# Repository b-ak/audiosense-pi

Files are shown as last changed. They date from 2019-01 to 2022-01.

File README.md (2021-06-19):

## AudioSense-Pi

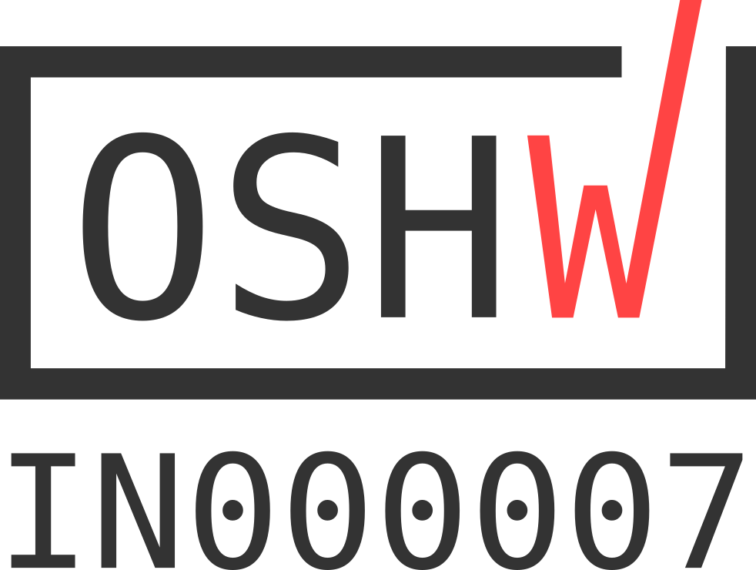
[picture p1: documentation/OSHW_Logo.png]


**[AudioSense-Pi](https://certification.oshwa.org/in000007.html)** is a RPi HAT based on a TI's stereo codec.  
It is **Open Source Harwdare Association (OSHWA)** certified with **_UID - IN000007_**  

This hardware provides audio input capabilities to the RPi.   
The codec connects to the RPi's SoC through the I2S Bus.

_The codec chosen, allows interfacing **multiple audio I/O** to the RPi._   

**Multiple I/O?** _Yes!_   
The following devices can be connected through a 3.5mm jack
1. Line-In: Plain old audio in from mobile phones, PCs, etc.,
2. Mic-In: Connect a microphone
3. Line-Out: Connect the output to a speaker
4. Headphones: Connect a Headphone w or w/o microphones

**Simultaneous Inputs?** _Yes!_    
It supports the following combinations
1. Two stereo Line-Inputs and a microphone
2. One stereo Line-Input and two microphones
3. Two stereo Line-Inputs, a microphone and one mono line-input (with h/w hack)
4. One stereo Line-Input, two microphones and one mono line-input (with h/w hack)

**Simultaneous Outputs?** _Yes!_   
Audio output can be routed to the headphones or speakers (with additional hardware)

#### Hardware overview       
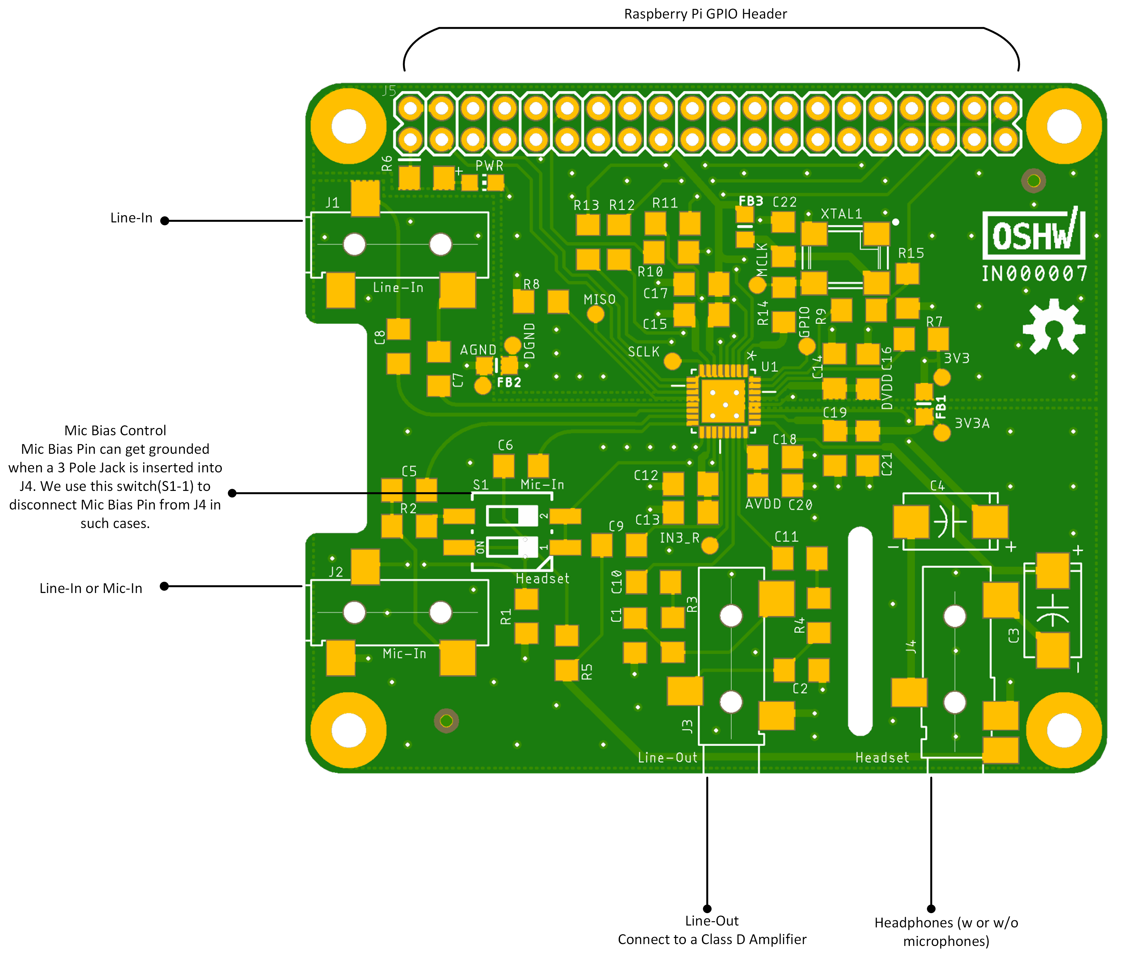
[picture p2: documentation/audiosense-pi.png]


#### Software overview   
Using the ALSA System on Chip (ASoC) layer we write a machine driver for the HAT.   
With the following changes a new sound card by the name `audiosense-pi` will appear
1. A device tree overlay is added for hardware configuration.
2. Changes to the configuration file (config.txt).
3. ASoC machine driver, makefile and kconfig changes
4. Minimal changes to the ASoC codec driver to handle deprecated APIs

## Getting started with AudioSense-Pi

#### Fab
1. Order the [BOM](./hardware/AudioSense-Pi_BOM.ods)
2. Send the [gerber files](./hardware/audiosense-pi-gerber.zip) to your nearest fab house
3. Assemble the board, it should look something like this..

Assembled Board    
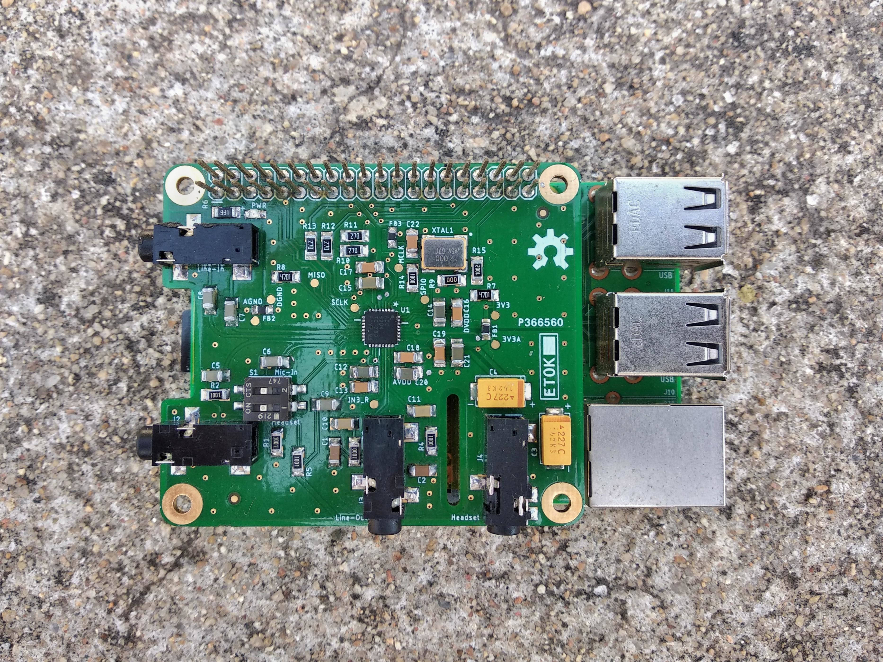
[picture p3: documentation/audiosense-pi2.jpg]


#### Preparing the SD card

We have three ways to setup audiosense
1. Get the [prebuilt images](https://drive.google.com/file/d/10sPdlaTlowZFA2HO4iOQT1hiyIX3uXNR/view?usp=sharing), flash it into a SD card, fly away!
2. Stay with the existing image you have, build the kernel yourself and flash only the kernel image
    * Pull the raspberry pi [kernel source](https://github.com/raspberrypi/linux.git)
    * Use [this](https://github.com/b-ak/helper-scripts/blob/master/rpi3-kernel-builder.sh) script to build and flash the kernel image to the SD card
    * Edit/add the following lines to the `config.txt` in the boot partiton of the SD card
    ```
        # Uncomment some or all of these to enable the optional hardware interfaces
        dtparam=i2c_arm=on
        dtparam=i2s=on
        dtparam=spi=on
        
        # Uncomment this to enable the lirc-rpi module
        #dtoverlay=lirc-rpi
        
        # Additional overlays and parameters are documented /boot/overlays/README
        dtoverlay=audiosense-pi

        # Enable audio (loads snd_bcm2835)
        dtparam=audio=on
    ```    
    * Boot the pi, run the command `aplay -l` you should see a new soundcard `audiosense-pi`
3. Get a kernel image that you want, merge the patches manually, build and flash the kernel image (*for advanced kernel developers*)
    * Clone the kernel sources you want
    * Apply the patches in the [software directory](./software) (`git am` might not work owing to the large number of changes among the trees)
    * Use the script in step 2, apply the `config.txt` changes and boot the pi

#### Configuring the soundcard
1. Open terminal, type in `alsamixer`. Hit `F6` and select `audiosense-pi` from the list of soundcards
	Soundcard selection    
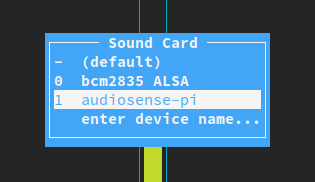
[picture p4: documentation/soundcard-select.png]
	
2. Soundcard widgets and control settings    
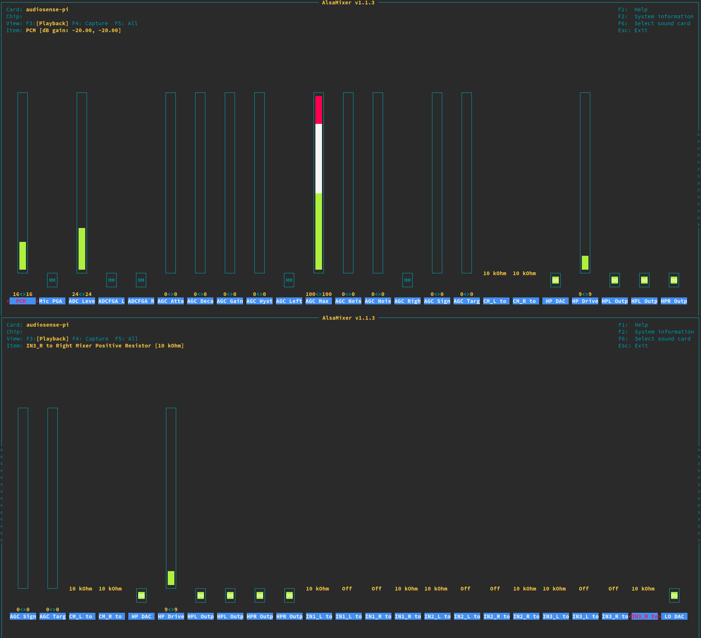
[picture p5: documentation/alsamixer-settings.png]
	
3. Plug in an audio-input to the board, a headphones and run `arecord -D hw:1 -c 2 -r 48000 -f S16_LE | aplay -D hw:1`
4. If you did everything right, you will be listening to your favourite song ;)

## License Information  

*Hardware* licensed under the _CERN Open Hardware License version 1.2_   
*Software* licensed under the _GNU GPLv2_   
*Documentation* licensed under _CC0 1.0 Universal_

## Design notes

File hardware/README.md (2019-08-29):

## AudioSense-Pi Hardware 

**Schematics**       


**Board**       


**PCB Top**       


**PCB Bottom**       


**Assembly**      
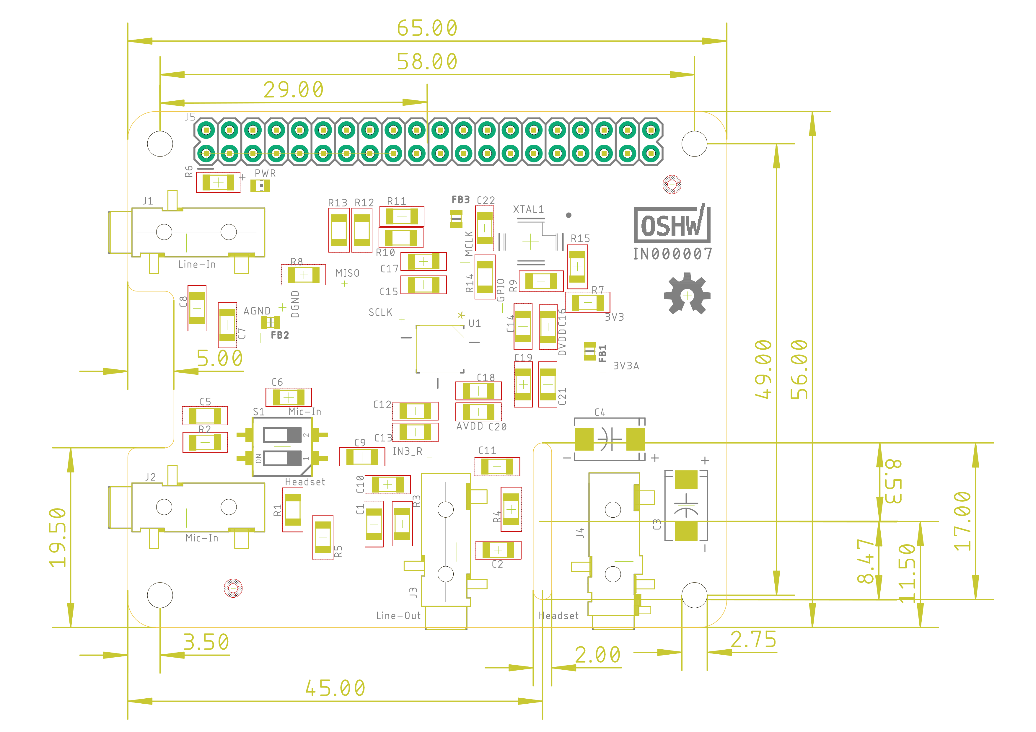
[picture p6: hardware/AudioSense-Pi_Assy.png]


## License Information  

*Hardware* licensed under the _CERN Open Hardware License version 1.2_   
*Software* licensed under the _GNU GPLv2_   
*Documentation* licensed under _CC0 1.0 Universal_

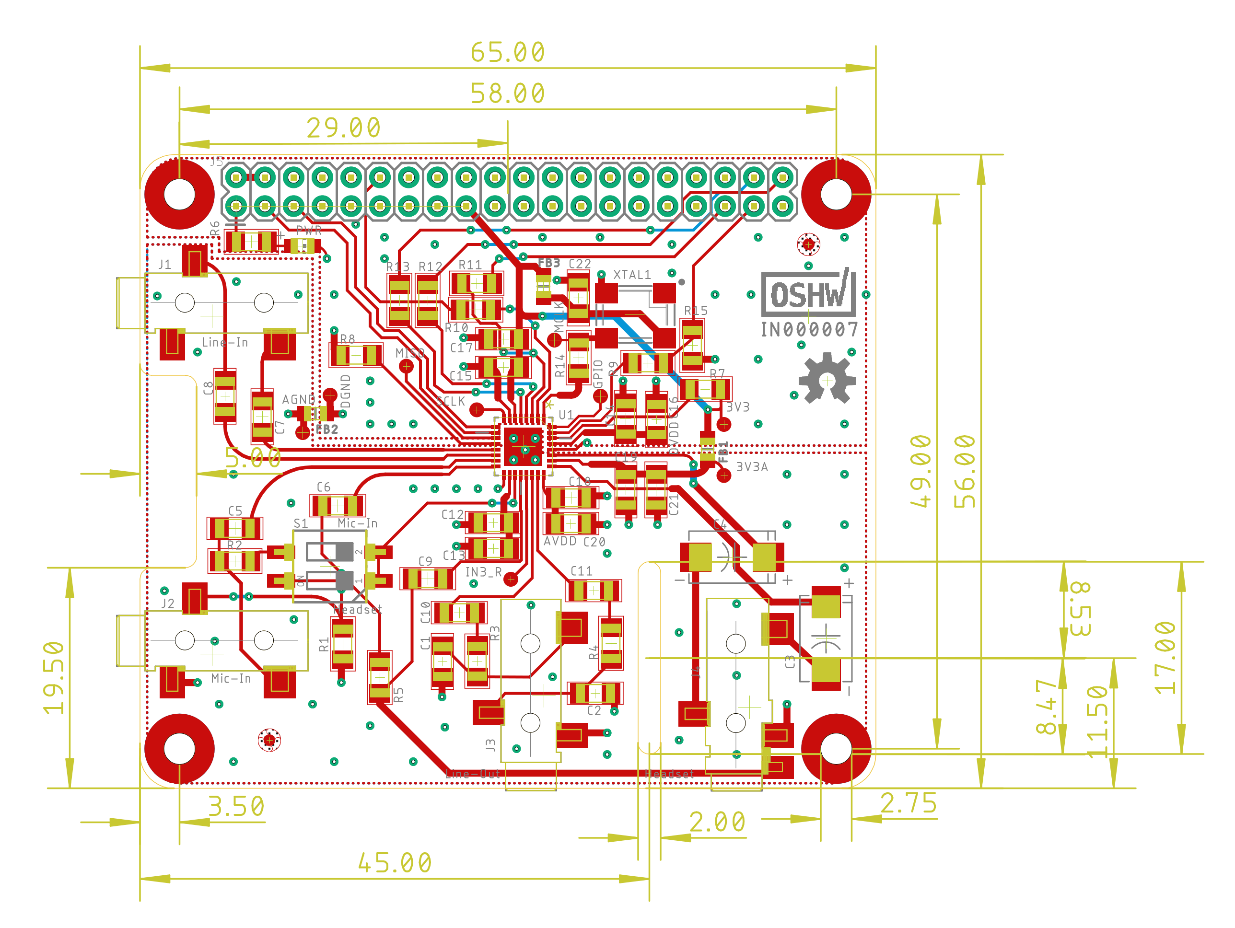
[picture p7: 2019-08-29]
documentation/AudioSense-Pi_Brd.png

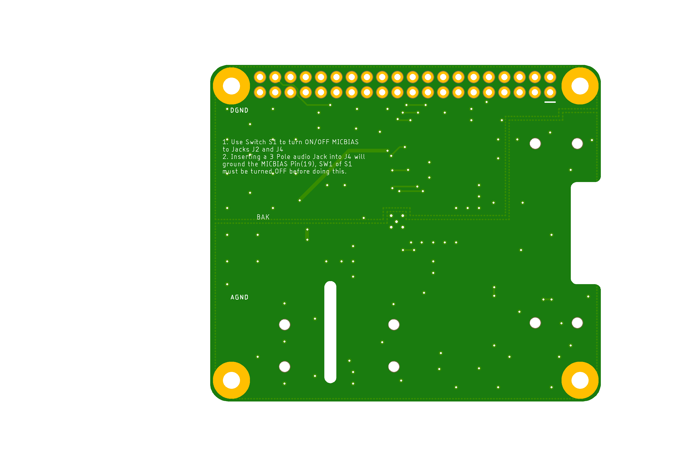
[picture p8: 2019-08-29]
documentation/AudioSense-Pi_PCB_Bot.png

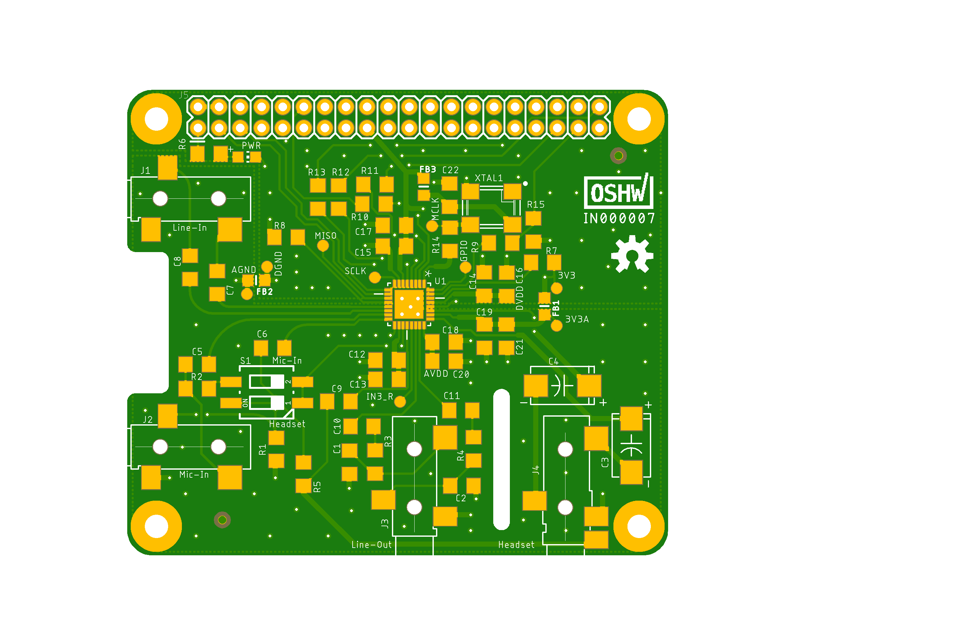
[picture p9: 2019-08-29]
documentation/AudioSense-Pi_PCB_Top.png

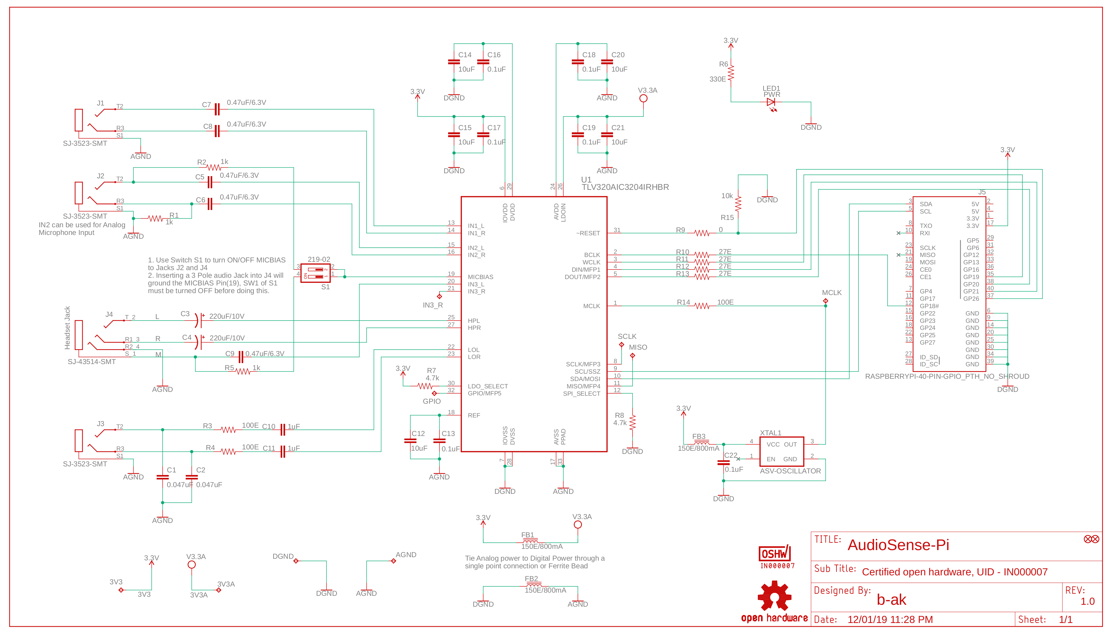
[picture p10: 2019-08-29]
documentation/AudioSense-Pi_Sch.png

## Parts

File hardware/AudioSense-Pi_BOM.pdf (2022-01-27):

### Page

Qty | Value | Parts | DESCRIPTION | MANUFACTURER | MANUFACTURER_PART_NUMBER | PACKAGE
9 | TPB1,27 | 3V3, 3V3A, AGND, DGND, GPIO, IN3_R, MCLK, MISO, SCLK
6 | 0.1uF | C13, C16, C17, C18, C19, C22 | CAP CER 0.1UF 16V X7R 1206 | Kemet | C1206C104K4RACTU | 1206
5 | 0.47uF/6.3V | C5, C6, C7, C8, C9 | CAP CER 0.47UF 16V X7R 1206 | Yageo | CC1206KRX7R7BB474 | 1206
5 | 10uF | C12, C14, C15, C20, C21 | CAP CER 10UF 16V X7R 1206 | Kemet | C1206C106J4RACTU | 1206
4 | 27E | R10, R11, R12, R13 | RES SMD 27 OHM 5% 1/4W 1206 | Yageo | RC1206JR-0727RL | 1206
3 | 100E | R3, R4, R14 | RES SMD 100 OHM 1% 1/4W 1206 | Yageo | RC1206FR-07100RL | 1206
3 | 150E/800mA | FB1, FB2, FB3 | FERRITE BEAD 150 OHM 0805 1LN | Murata Electronics North America | BLM21AG151SN1D | 0805 (2012 Metric)
3 | 1k | R1, R2, R5 | RES SMD 1K OHM 1% 1/4W 1206 | Yageo | RC1206FR-071KL | 1206
3 | SJ-3523-SMT | J1, J2, J3 | CONN JACK STEREO 3.5MM SMD R/A | CUI Inc. | SJ-3523-SMT-TR | Surface Mount, Right Angle
2 | 0.047uF | C1, C2 | CAP CER 0.047UF 10V X7R 1206 | AVX Corporation | 1206ZC473KAT2A | 1206
2 | 1uF | C10, C11 | CAP CER 1UF 16V X7R 1206 | Yageo | CC1206JKX7R7BB105 | 1206
2 | 220uF/10V | C3, C4 | CAP TANT 220UF 10V 10% 2917 | KEMET | T491D227K010AT | 2917 (7343 Metric)
2 | 4.7k | R7, R8 | RES SMD 4.7K OHM 1% 1/4W 1206 | Yageo | RC1206FR-074K7L | 1206
2 | FIDUCIAL" | FID1, FID2
1 | 0 | R9 | RES SMD 0 OHM JUMPER 1/4W 1206 | Yageo | AC1206JR-070RL | 1206
1 | 10k | R15 | RES SMD 10K OHM 1% 1/4W 1206 | Yageo | RC1206FR-0710KP | 1206
1 | 219-02 | S1 | SWITCH SLIDE DIP SPST 100MA 20V | CTS Electrocomponents | 219-2LPSTR | SMT
1 | 330E | R6 | RES SMD 330 OHM 5% 1/4W 1206 | Yageo | RC1206JR-07330RL | 1206
1 | ASV-OSCILLATOR | XTAL1 | OSC XO 12.000MHZ HCMOS SMD | Abracon LLC | ASV-12.000MHZ-EJ-T | 1206
1 | LED1 | PWR | | Lite-On Inc. | | 0805 (2012 Metric)
1 | OSHW-LOGOL | LOGO1
1 | RASPBERRYPI-40-PIN-GPIO_PTH_NO_SHROUD | J5 | Stacking Header for Pi A+/B+/Pi 2/Pi 3 -2x20 Extra Tall Header | Adafruit | 1979 | PTH
1 | SJ-43514-SMT | J4 | CONN JACK 4COND 3.5MM SMD R/A | CUI Inc. | SJ-43514-SMT-TR | Surface Mount, Right Angle
1 | TLV320AIC3204IRHBR | U1 | IC STEREO AUDIO CODEC 1.8V 32QFN | Texas Instruments | TLV320AIC3204IRHBR | 32-VFQFN Exposed Pad

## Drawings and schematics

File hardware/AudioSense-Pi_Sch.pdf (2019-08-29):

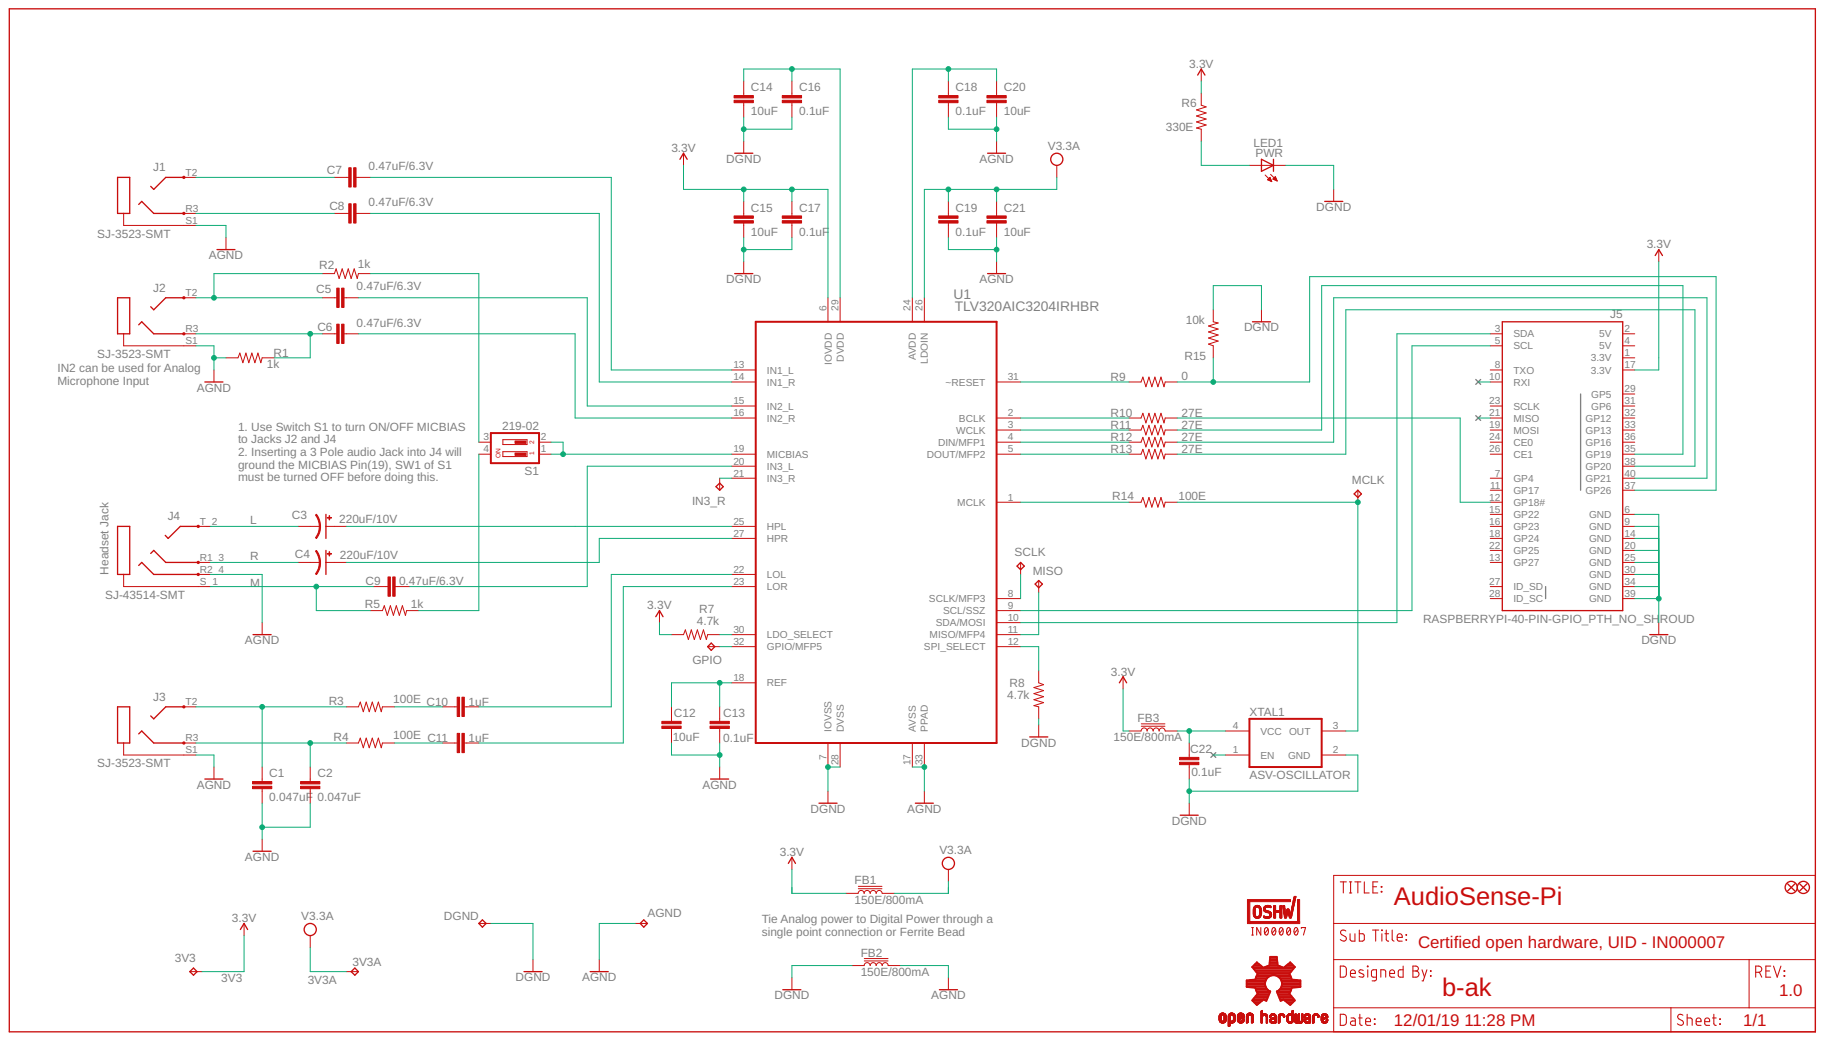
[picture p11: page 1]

IN2 can be used for Analog Microphone Input

1. Use Switch S1 to turn ON/OFF MICBIAS
to Jacks J2 and J4
2. Inserting a 3 Pole audio Jack into J4 will ground the MICBIAS Pin(19), SW1 of S1 must be turned OFF before doing this.

Tie Analog power to Digital Power through a
single point connection or Ferrite Bead

Certified open hardware, UID - IN000007

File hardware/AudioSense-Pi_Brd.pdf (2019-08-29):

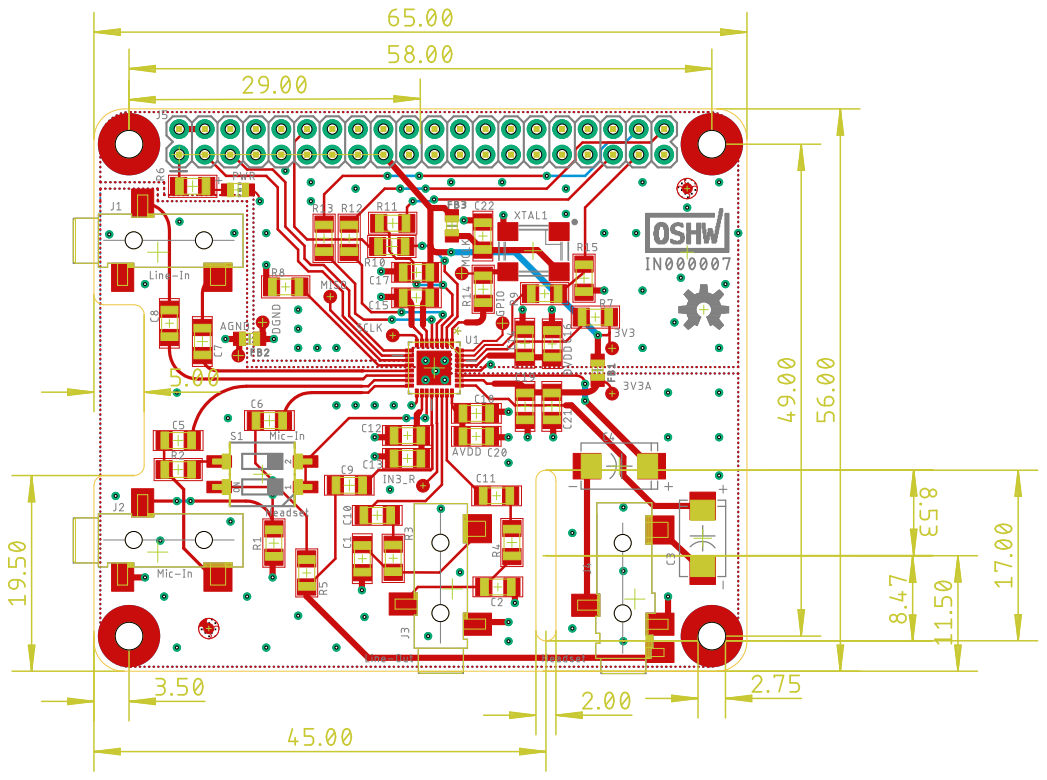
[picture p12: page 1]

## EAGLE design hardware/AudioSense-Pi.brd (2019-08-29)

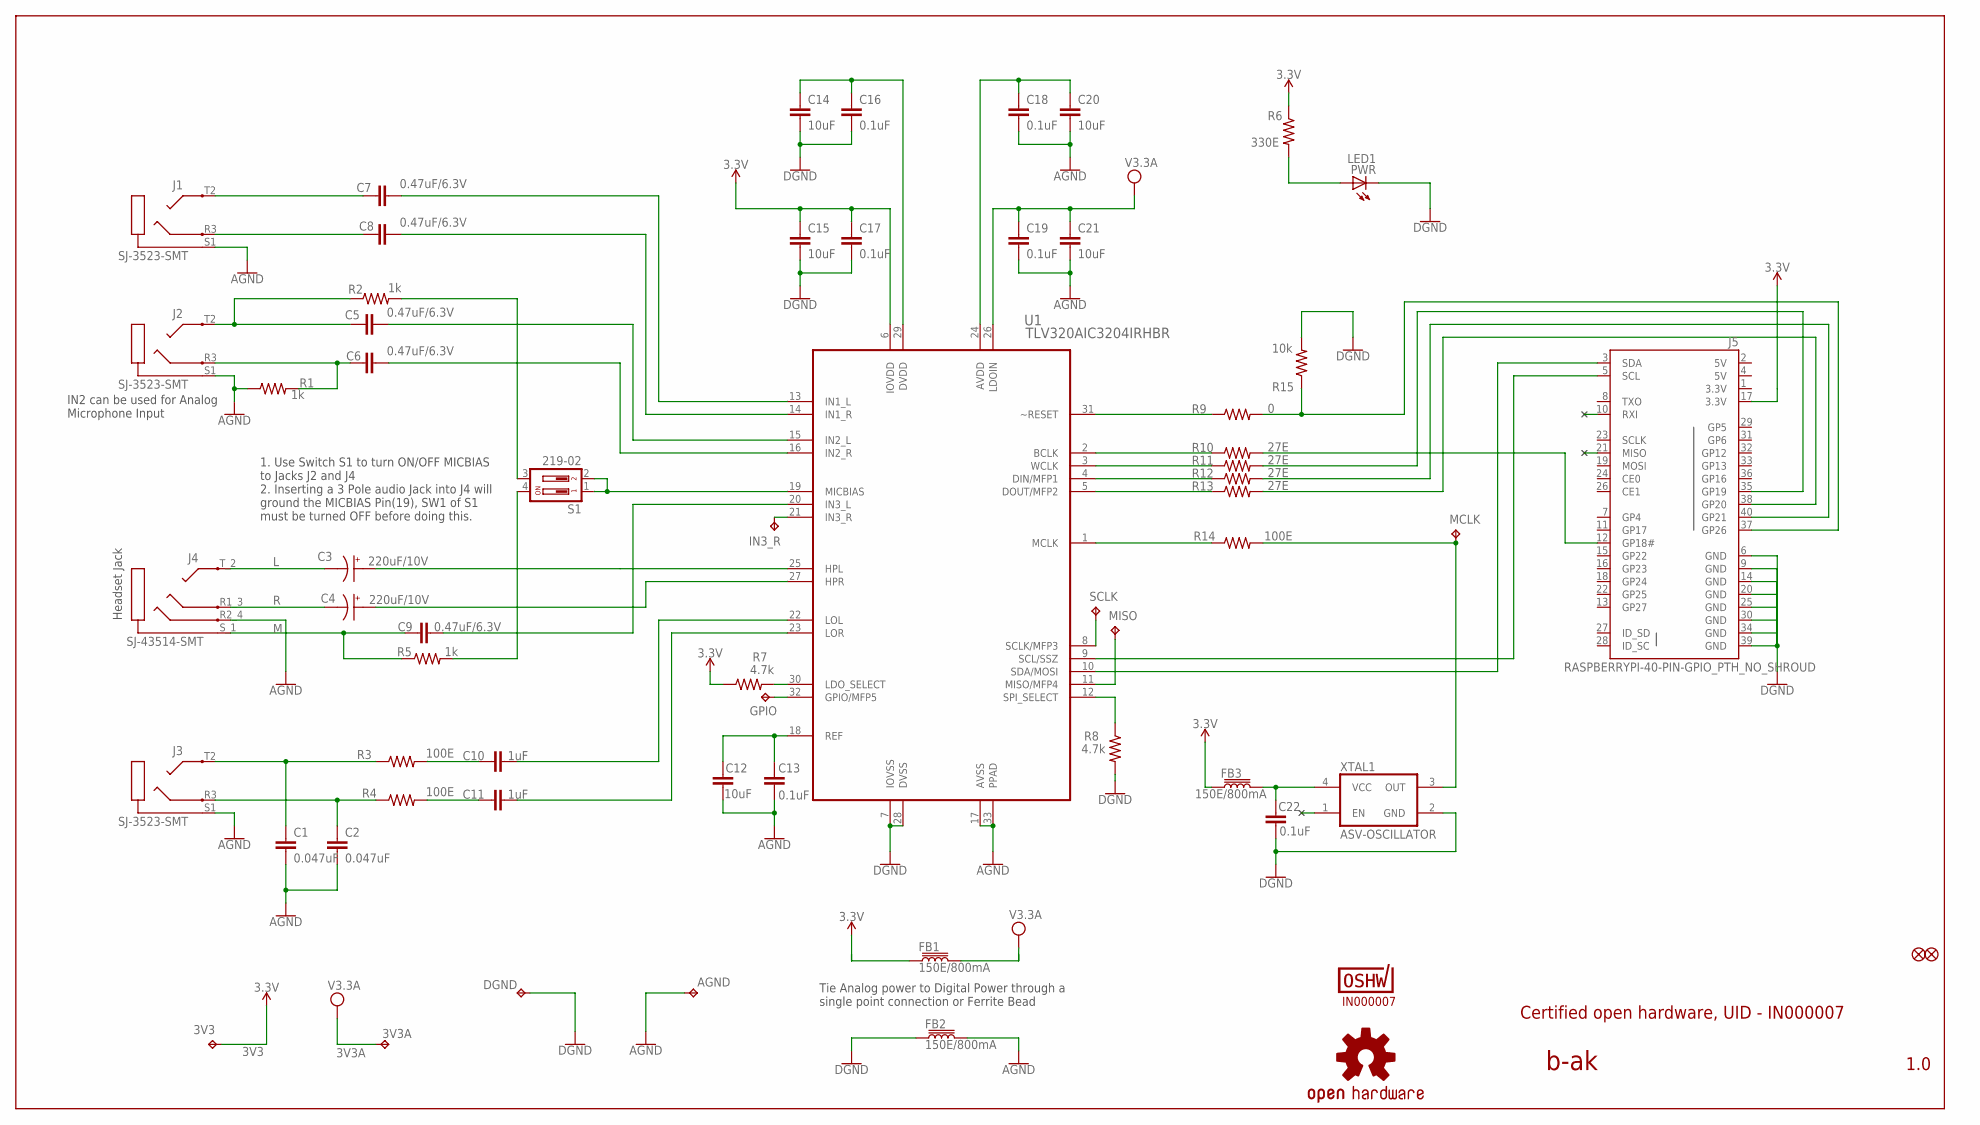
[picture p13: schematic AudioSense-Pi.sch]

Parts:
3V3, 3V3A: TPB1,27; B1,27
AGND: TPB1,27; B1,27
C1, C2: 0.047uF; C1206; MANUFACTURER_PART_NUMBER 1206ZC473KAT2A
C3, C4: 220uF/10V; D; MANUFACTURER_PART_NUMBER T491D227K010AT
C5, C6, C7, C8, C9: 0.47uF/6.3V; C1206; MANUFACTURER_PART_NUMBER CC1206KRX7R7BB474
C10, C11: 1uF; C1206; MANUFACTURER_PART_NUMBER CC1206JKX7R7BB105
C12, C14, C15, C20, C21: 10uF; C1206; MANUFACTURER_PART_NUMBER C1206C106J4RACTU
C13, C16, C17, C18, C19, C22: 0.1uF; C1206; MANUFACTURER_PART_NUMBER C1206C104K4RACTU
DGND: TPB1,27; B1,27
FB1, FB2, FB3: 150E/800mA; _0805MP; MANUFACTURER_PART_NUMBER BLM21AG151SN1D
FID1, FID2: FIDUCIAL""; FIDUCIAL_1MM
GPIO: TPB1,27; B1,27
IN3_R: TPB1,27; B1,27
J1, J2, J3: SJ-3523-SMT; MANUFACTURER_PART_NUMBER SJ-3523-SMT-TR
J4: SJ-43514-SMT; MANUFACTURER_PART_NUMBER SJ-43514-SMT-TR
J5: RASPBERRYPI-40-PIN-GPIO_PTH_NO_SHROUD; 2X20; MANUFACTURER_PART_NUMBER 1979
LOGO2: OSHW-LOGOM; OSHW-LOGO-M
MCLK: TPB1,27; B1,27
MISO: TPB1,27; B1,27
PWR: LED1; CHIP-LED0805; MANUFACTURER_PART_NUMBER LTST-C150GKT
R1, R2, R5: 1k; 1206; MANUFACTURER_PART_NUMBER RC1206FR-071KL
R3, R4, R14: 100E; 1206; MANUFACTURER_PART_NUMBER RC1206FR-07100RL
R6: 330E; 1206; MANUFACTURER_PART_NUMBER RC1206JR-07330RL
R7, R8: 4.7k; 1206; MANUFACTURER_PART_NUMBER RC1206FR-074K7L
R9: 0; 1206; MANUFACTURER_PART_NUMBER AC1206JR-070RL
R10, R11, R12, R13: 27E; 1206; MANUFACTURER_PART_NUMBER RC1206JR-0727RL
R15: 10k; 1206; MANUFACTURER_PART_NUMBER RC1206FR-0710KP
S1: 219-02; CTS-219-02
SCLK: TPB1,27; B1,27
U1: TLV320AIC3204IRHBR; QFN50P500X500X100-33N; MANUFACTURER_PART_NUMBER TLV320AIC3204IRHBR
U$6: IN000007; CERT-SMALL-SILK
XTAL1: ASV-OSCILLATOR; OSCILLATOR_7X5_SMD; MANUFACTURER_PART_NUMBER ASV-12.000MHZ-EJ-T

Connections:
3POLE_MBIAS: R2.2, S1.3
3V3: 3V3.TP, C15.1, C17.1, FB1.1, FB3.1, J5.1 (3.3V), J5.17 (3.3V), R6.1, R7.1, U1.6 (IOVDD)
3V3A: 3V3A.TP, C19.1, C21.1, FB1.2, U1.26 (LDOIN)
4POLE_MBIAS: R5.2, S1.4
5V: J5.2 (5V), J5.4 (5V)
AGND: AGND.TP, C1.2, C2.2, C12.2, C13.2, C18.2, C19.2, C20.2, C21.2, FB2.2, J1.S1, J2.S1, J3.S1, J4.R2_4, R1.1, U1.17 (AVSS), U1.33 (PPAD)
AIC_LINE_LOUT_1: C10.1, R3.2
AIC_LINE_ROUT_1: C11.1, R4.2
AVDD: C18.1, C20.1, U1.24 (AVDD)
BCLK: R10.1, U1.2 (BCLK)
DIN: R12.1, U1.4 (DIN/MFP1)
DOUT: R13.1, U1.5 (DOUT/MFP2)
DVDD: C14.1, C16.1, U1.29 (DVDD)
GND: C14.2, C15.2, C16.2, C17.2, C22.2, DGND.TP, FB2.1, J5.6 (GND), J5.9 (GND), J5.14 (GND), J5.20 (GND), J5.25 (GND), J5.30 (GND), J5.34 (GND), J5.39 (GND), PWR.C, R8.2, R15.2, U1.7 (IOVSS), U1.28 (DVSS), XTAL1.2 (GND)
GPIO: GPIO.TP, U1.32 (GPIO/MFP5)
GP_26: J5.37 (GP26), R9.2, R15.1
HPL: C3.+ (A), U1.25 (HPL)
HPR: C4.+ (A), U1.27 (HPR)
IN1L: C7.2, U1.13 (IN1_L)
IN1R: C8.2, U1.14 (IN1_R)
IN1_RING: C8.1, J1.R3
IN1_TIP: C7.1, J1.T2
IN2L: C5.2, U1.15 (IN2_L)
IN2R: C6.2, U1.16 (IN2_R)
IN2_RING: C6.1, J2.R3, R1.2
IN2_TIP: C5.1, J2.T2, R2.1
IN3L: C9.2, U1.20 (IN3_L)
IN3_R: IN3_R.TP, U1.21 (IN3_R)
L: C3.- (C), J4.T_2
LDO_SEL: R7.2, U1.30 (LDO_SELECT)
LED-A: PWR.A, R6.2
LOL: C10.2, U1.22 (LOL)
LOR: C11.2, U1.23 (LOR)
LOUT_RING: C2.1, J3.R3, R4.1
LOUT_TIP: C1.1, J3.T2, R3.1
M: C9.1, J4.S_1, R5.1
MCLK: R14.1, U1.1 (MCLK)
MICBIAS: S1.1, S1.2, U1.19 (MICBIAS)
MISO: MISO.TP, U1.11 (MISO/MFP4)
R: C4.- (C), J4.R1_3
REF: C12.1, C13.1, U1.18 (REF)
RESET: R9.1, U1.31 (~RESET)
RPI_BCLK_PIN12: J5.12 (GP18#), R10.2
RPI_DIN_PIN38: J5.38 (GP20), R13.2
RPI_DOUT_PIN40: J5.40 (GP21), R12.2
RPI_FS_PIN35: J5.35 (GP19), R11.2
SCL: J5.5 (SCL), U1.9 (SCL/SSZ)
SCLK: SCLK.TP, U1.8 (SCLK/MFP3)
SDA: J5.3 (SDA), U1.10 (SDA/MOSI)
SPI_SEL: R8.1, U1.12 (SPI_SELECT)
VCC: C22.1, FB3.2, XTAL1.4 (VCC)
WCLK: R11.1, U1.3 (WCLK)
XTAL_OUT: MCLK.TP, R14.2, XTAL1.3 (OUT)

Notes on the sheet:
Tie Analog power to Digital Power through a single point connection or Ferrite Bead
b-ak
1. Use Switch S1 to turn ON/OFF MICBIAS to Jacks J2 and J4 2. Inserting a 3 Pole audio Jack into J4 will ground the MICBIAS Pin(19), SW1 of S1 must be turned OFF before doing this.
IN2 can be used for Analog Microphone Input
Headset Jack
1.0
Certified open hardware, UID - IN000007

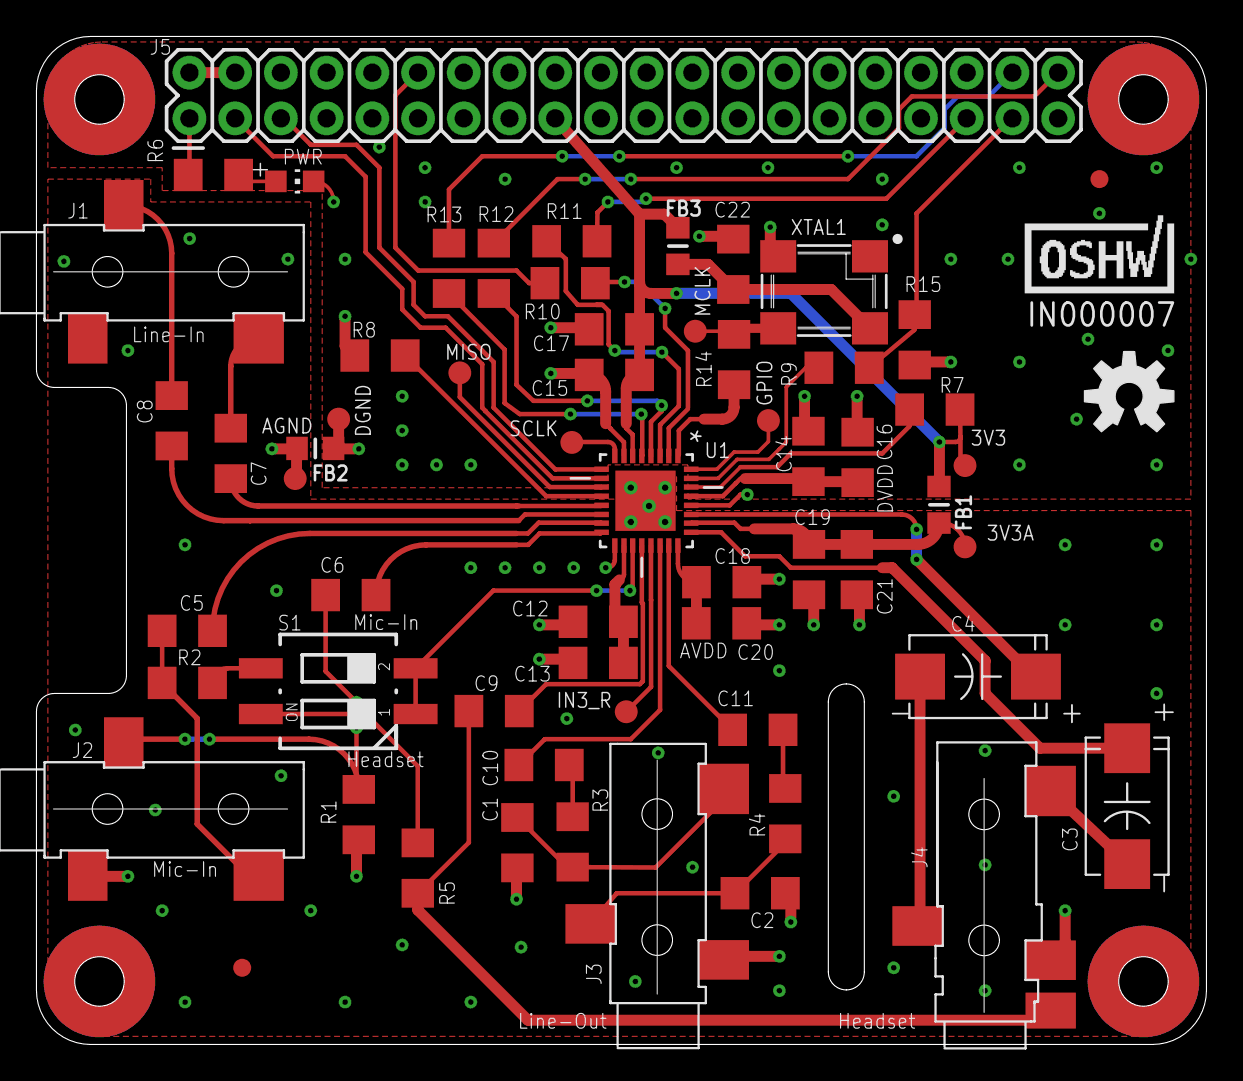
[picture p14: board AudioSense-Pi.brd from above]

Board: 2 copper layers, 65.0 x 56.0 mm, 62 parts (0 on the bottom side), 53 nets.

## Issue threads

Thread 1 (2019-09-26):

No audio on PH and Line output

sawacs, 2019-09-26:
Hi.
My hardware: RaspberryPi 4/4GB with latest Raspbian kernel 4.19.

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

I have two AudioSense-Pi that I have assembled myself.

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

I added all necessary entries to /boot/config.txt:
dtparam=i2c_arm=on
dtparam=i2s=on
dtparam=spi=on
dtoverlay=lirc-rpi
dtoverlay=audiosense-pi

My problem is that there is no audio signal on both headphone and line outputs.

Test i did:

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

1: ffmpeg -i Downloads/1kHz_44100Hz_16bit_30sec.wav -af "pan=stereo|c0=c0|c1=c0" -ar 48000 -f alsa hw:1,0

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

 No audio output! I noticed that "time" increases every two to three seconds and "speed" drops from 0.99 downwards v. fast...
It's the same for both PCBs
Perhaps something is wrong on the PCB, but all the elements were new and I tried to assemble them very carefully!
I'm sure raspbian os recognizes AudioSense-Pi correctly. I carried out the test by giving an audio signal to the LineIn input and switched "Bypass" - HPL / R Output Mixer IN1L / R
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
I heard on the headphones what was on the line input... I2C is working...
OK.
For today I have to finish ...

Maybe someone has an idea where is the problem ....?
Or maybe someone already had such a problem ...?

By

b-ak, 2019-09-28:
Can you try this command `arecord -D hw:1 -c 2 -r 48000 -f S16_LE | aplay -D hw:1`
Connect an audio source to `J2` - `Mic-In` and check what's on your headphones

sawacs, 2019-09-30:
Hi!
There was a problem here
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
... I soldered two resistors R10 and R11 wrongly!
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

Now I'm going to tests ...

b-ak, 2019-10-03:
Great!! Any updates? Have you got it working?

sawacs, 2019-10-04:
I apologize for the short delay in my response ... I was away for a few days.
Yes. I confirm that my tests were successful. Recording works, playback works. Now I am learning the other possibilities of TLV320 ...
Thanks for the help.
... I will try to run modules on OrangePi and NanoPi M4 after some time.

b-ak, 2019-10-06:
Great to know that. Thank you for a detailed report, it'll help other people trying to recreate the board :)

Closed 2019-10-04.

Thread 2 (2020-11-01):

Playback not working, getting input/output error

SlowFamily, 2020-11-01:
I have acquired a Raspberry Pi 3 Model B+ in order to test. Unfortunately, I am still having no success getting audiosense-pi to work. :-(

I am trying to use Linux raspberrypi 4.19.118-v7+ #1311

If I have headphones plugged in when I power it up, I hear a pop, and power light is on, so it is at least getting power.

I see devices like so:

$ aplay -l
**** List of PLAYBACK Hardware Devices ****
card 0: Headphones [bcm2835 Headphones], device 0: bcm2835 Headphones [bcm2835 Headphones]
Subdevices: 8/8
Subdevice #0: subdevice #0
Subdevice #1: subdevice #1
Subdevice #2: subdevice #2
Subdevice #3: subdevice #3
Subdevice #4: subdevice #4
Subdevice #5: subdevice #5
Subdevice #6: subdevice #6
Subdevice #7: subdevice #7
card 1: audiosensepi [audiosense-pi], device 0: TLV320AIC3204 Hifi Audio tlv320aic32x4-hifi-0 [TLV320AIC3204 Hifi Audio tlv320aic32x4-hifi-0]
Subdevices: 1/1
Subdevice #0: subdevice #0

When attempting to play audio file, I hear nothing in headphones and get error eventually:

$ aplay -D hw:1 archer-theme-song-16bit-pcm.wav
Playing WAVE 'archer-theme-song-16bit-pcm.wav' : Signed 16 bit Little Endian, Rate 48000 Hz, Stereo
aplay: pcm_write:2053: write error: Input/output error

Do you have any suggestions how to troubleshoot?

SlowFamily, 2021-01-07:
Are there any particular settings in alsamixer that need to be enabled? There are a lot of items in there that I do not understand what they do. I have tried to ensure nothing is muted, but maybe something needs to be turned up?

b-ak, 2021-01-29:
I will upload my image over the weekend. Please give it a try. Seems to be something basic that you are missing..

SlowFamily, 2021-02-06:
> I will upload my image over the weekend. Please give it a try. Seems to be something basic that you are missing..

Where is image uploaded to? I attempted to click link to Google Drive in the README but seems to still not exist on that link.

b-ak, 2021-02-09:
Here's the image
https://drive.google.com/file/d/10sPdlaTlowZFA2HO4iOQT1hiyIX3uXNR/view?usp=sharing

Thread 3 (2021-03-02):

Audiosense-pi not loaded anymore after kernel update: 5.4.x to 5.10

linuxchris12, 2021-03-02:
it is working again after downgrading with:

`sudo rpi-update 453e49bdd87325369b462b40e809d5f3187df21d`

linuxchris12, 2021-03-10:
Workaround for the 5.10 kernel:

`
sound/soc/codecs/tlv320aic32x4.c | 4 ++--
 1 file changed, 2 insertions(+), 2 deletions(-)

diff --git a/sound/soc/codecs/tlv320aic32x4.c b/sound/soc/codecs/tlv320aic32x4.c
index 9e3de9ded..5ac1418d7 100644
--- a/sound/soc/codecs/tlv320aic32x4.c
+++ b/sound/soc/codecs/tlv320aic32x4.c
@@ -1233,7 +1233,7 @@ int aic32x4_probe(struct device *dev, struct regmap *regmap)
 		return ret;
 	}

-	if (gpio_is_valid(aic32x4->rstn_gpio)) {
+	/* if (gpio_is_valid(aic32x4->rstn_gpio)) {
 		ndelay(10);
 		gpio_set_value_cansleep(aic32x4->rstn_gpio, 1);
 		mdelay(1);
@@ -1241,7 +1241,7 @@ int aic32x4_probe(struct device *dev, struct regmap *regmap)

 	ret = regmap_write(regmap, AIC32X4_RESET, 0x01);
 	if (ret)
-		goto err_disable_regulators;
+		goto err_disable_regulators; */

 	ret = devm_snd_soc_register_component(dev,
 			&soc_component_dev_aic32x4, &aic32x4_dai, 1);
--
2.29.2
`

b-ak, 2021-11-16:
These lines bring the codec out of reset. Is the codec still working with this fix?

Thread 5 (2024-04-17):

RPi4 GPIO 26 - Reset

AndyW999, 2024-04-17:
I have followed the instructions but GPIO pin 26 is set to an INPUT rather than a HIGH OUTPUT to bring the codec chip out of reset.

This means that nothing works!

Any ideas?

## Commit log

2019-08-29 Pushing all OSHW files here
    [AudioSense-Pi.brd, AudioSense-Pi.sch, AudioSense-Pi_BOM.ods]
2022-01-27 ODS viewer not available in Ubuntu, PDF version of BOM..

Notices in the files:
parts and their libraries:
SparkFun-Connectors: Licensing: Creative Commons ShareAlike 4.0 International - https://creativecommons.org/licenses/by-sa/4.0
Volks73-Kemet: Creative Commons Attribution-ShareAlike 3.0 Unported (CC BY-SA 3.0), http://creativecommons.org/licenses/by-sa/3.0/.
